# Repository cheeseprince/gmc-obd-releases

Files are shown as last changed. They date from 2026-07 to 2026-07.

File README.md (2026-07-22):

# GMC OBD Display — OTA Releases

Firmware release channel for an in-cab OBD-II stat display on a **2025 GMC Sierra 1500
3.0L Duramax** (LZ0, Global B). Binaries only — source is maintained privately.

The display shows live engine, transmission, aftertreatment and economy data pulled over
Bluetooth LE from a generic ELM327 adapter, including enhanced GM Mode-22 parameters
(transmission temperature, EGT, DPF differential pressure, fuel rail pressure, DEF level)
that generic scan tools do not expose.

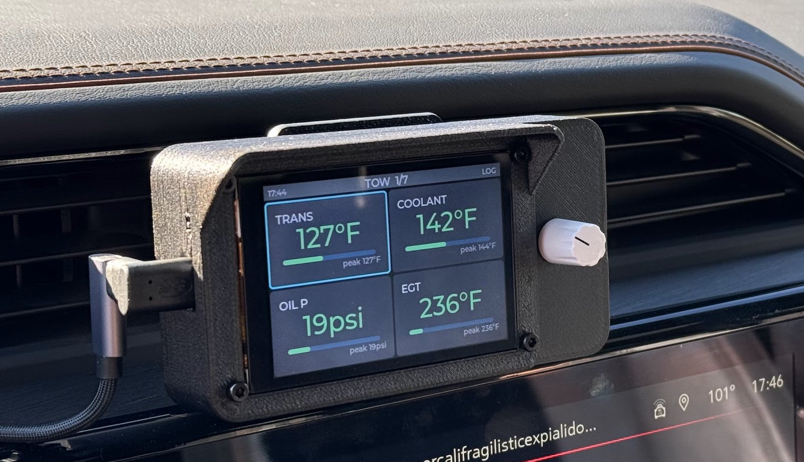
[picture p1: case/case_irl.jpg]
The unit installed on the dash, showing the towing page


## Hardware

| Part | Detail |
| :--- | :--- |
| **Display / MCU** | Elecrow **CrowPanel Advance 3.5"** — ESP32-S3-WROOM-1-N16R8 (16 MB flash, 8 MB PSRAM), 480×320 IPS |
| **Input** | Arduino **Modulino** rotary encoder (I²C) — rotate to move, press to zoom, long-press for settings |
| **Encoder cable** | **SparkFun Qwiic-to-Grove adapter cable, 100 mm** (`B082MM52ZR`) — the board exposes a Grove/Crowtail I²C port, the Modulino uses Qwiic; this bridges them |
| **Storage** | **microSD** card (FAT32) — 1 Hz CSV drive logs |
| **Clock** | On-board **PCF8563** real-time clock (I²C 0x51) with its coin cell — both ship with the CrowPanel. Timestamps the SD logs and drives automatic day/night theming |
| **OBD adapter** | **Vgate vLinker MS** in BLE mode (classic-CAN ELM327) — see tested adapters below |
| **Power** | Truck USB (switched 5 V) → board USB-C |
| **Case** | 3D printed — STLs in [`case/`](case/) — plus **8 × M3 heat-set threaded inserts** (4 mm long, 5 mm OD) and **8 × M3 × 10 mm screws** |

The capacitive touch panel is present but unused; all navigation is via the encoder.

### Case

Three-part printed enclosure — the CAD assembly, and the printed result on the dash
above.

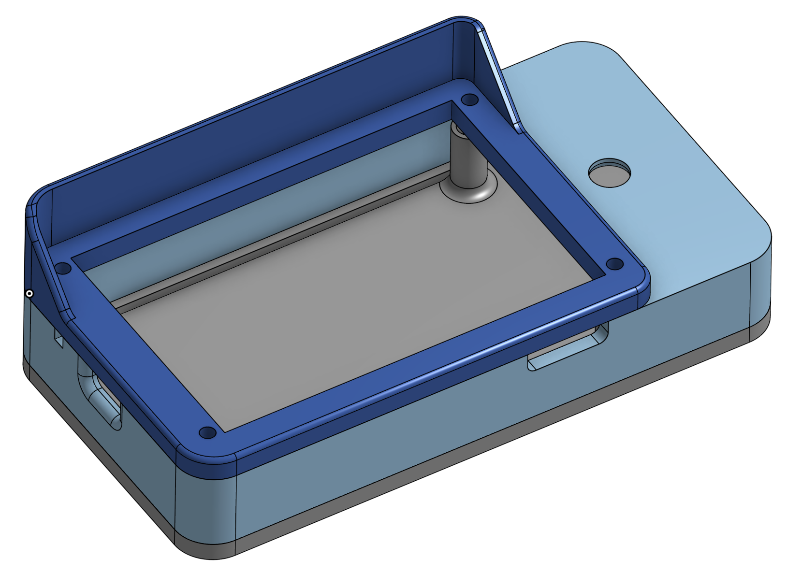
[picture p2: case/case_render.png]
Case assembly


Three printed parts: a bottom shell that carries the board on moulded standoffs, a frame
that captures the display bezel, and a top. Heat-set the inserts into the bottom, then the
screws pass down through the top and frame into them.

| Part | Footprint | STL |
| :--- | :--- | :--- |
| Top | 131.4 × 69.4 × 17.0 mm | [`CASE_TOP.stl`](case/CASE_TOP.stl) |
| Frame | 102.8 × 69.4 × 20.0 mm | [`CASE_FRAME.stl`](case/CASE_FRAME.stl) |
| Bottom | 131.4 × 69.4 × 19.0 mm | [`CASE_BOTTOM.stl`](case/CASE_BOTTOM.stl) |

Fasteners: **8 × M3 heat-set threaded inserts** (4 mm long, 5 mm OD) and
**8 × M3 × 10 mm screws**. Everything fits a 140 mm bed.

## Tested OBD adapters

Both were verified on the vehicle. **Addressing turned out to be adapter-dependent on
this truck** — worth knowing before assuming a working adapter implies a working
protocol configuration.

| Adapter | Link | Result |
| :--- | :--- | :--- |
| **Vgate vLinker MS** | BLE | **In use.** Reads enhanced GM Mode-22 with **11-bit** headers (`7DF` functional, `7E0` engine, `7E2` transmission). Also works in classic-Bluetooth mode on ESP32 (non-S3) boards. |
| **Vgate iCar Pro WiFi** | Wi-Fi SoftAP | **Works, but only on 29-bit CAN.** Same truck, same PIDs, different addressing: ISO 15765-4 29-bit/500k (`18DB33F1` functional, `18DAxxF1` physical). Defaults: SSID `V-LINK`, TCP `192.168.0.10:35000`. |

Notes from bring-up:

- The vLinker MS ships in **Classic/MFi-only** mode. An ESP32-**S3** has no classic
  Bluetooth, so the adapter must first be switched to BT+BLE mode with Vgate's
  `VgateFwUpdater` app — a one-time change. Its ELM327 service is GATT `0x18F0`
  (notify `0x2AF0`, write `0x2AF1`).
- A generic adapter's protocol auto-search is aborted by **any** host character, so the
  first `0100` after `ATSP0` needs a multi-second window. A short timeout latches the
  wrong protocol and every PID then returns `NO DATA`.
- A single BLE OBD adapter bonds to **one** client at a time.

## The display

Pixel-exact renders of the real firmware UI — generated on the build machine by
compiling the actual UI code against LVGL, so they match the panel exactly.

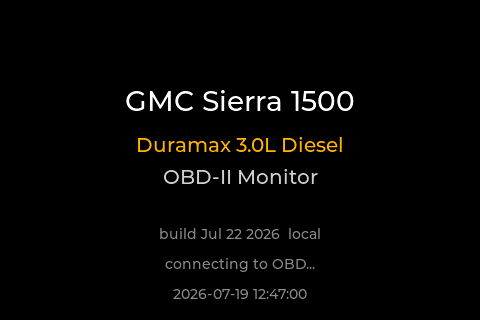
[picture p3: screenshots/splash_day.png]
Boot splash


Seven pages of four tiles, grouped by what you're doing. Rotate the encoder to move the
cursor; it flows across pages in reading order.

| TOW | POWER |
| :---: | :---: |
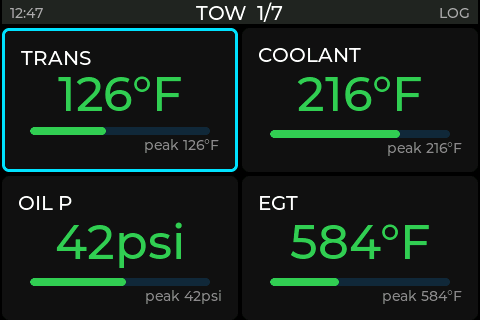
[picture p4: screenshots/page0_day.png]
TOW page
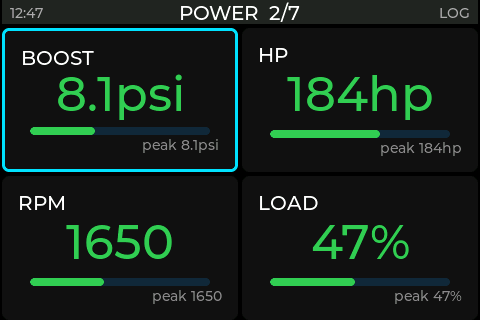
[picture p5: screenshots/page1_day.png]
POWER page
|  |  |
| Transmission · coolant · oil pressure · EGT | Boost · horsepower · RPM · engine load |

| REGEN | RANGE |
| :---: | :---: |
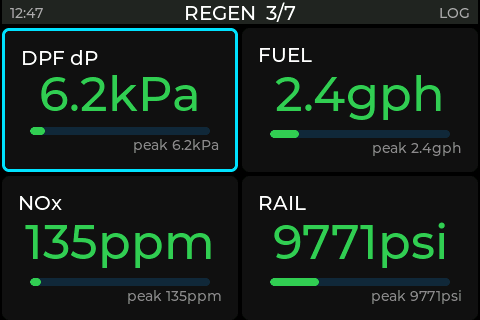
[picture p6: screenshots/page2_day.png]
REGEN page
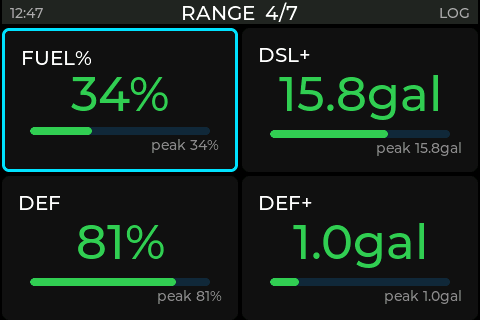
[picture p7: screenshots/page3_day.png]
RANGE page
|  |  |
| DPF Δp · fuel rate · NOx · rail pressure | Fuel and DEF level, plus gallons-to-fill |

| TRIP | DIAG | MISC |
| :---: | :---: | :---: |
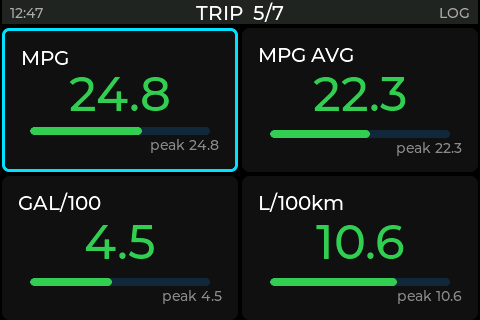
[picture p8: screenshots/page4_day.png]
TRIP page
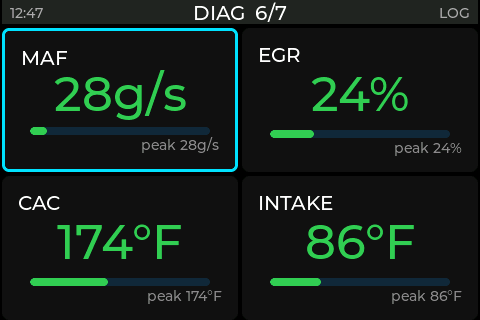
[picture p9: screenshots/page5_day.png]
DIAG page
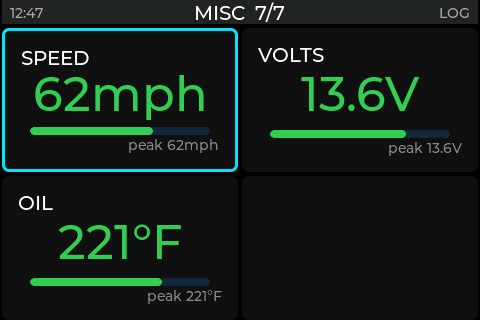
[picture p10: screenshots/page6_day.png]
MISC page
|  |  |  |
| Instant and average economy, in both US and metric units | MAF · EGR · charge-air cooler temp · intake temp | Speed · battery voltage · oil temperature |

Press the encoder to zoom a single tile, with a five-minute trend graph coloured by alarm
zone. Hold it for settings.

| Focus view | Settings |
| :---: | :---: |
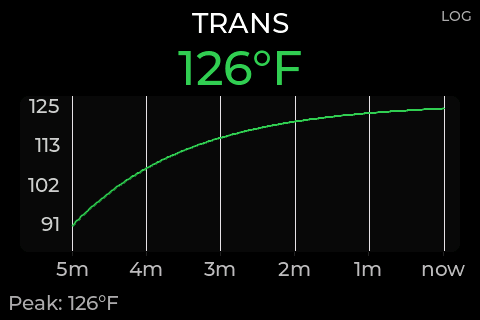
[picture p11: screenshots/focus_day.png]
Focus view
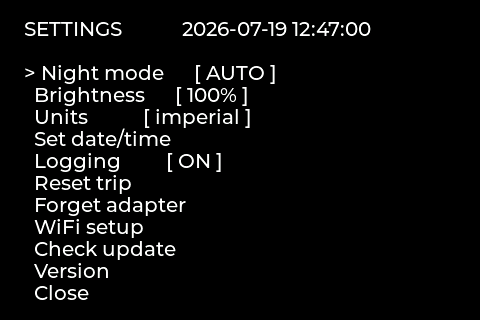
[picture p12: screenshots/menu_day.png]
Settings menu
|  |  |

The theme follows sunrise and sunset automatically, computed on-device from the real-time
clock — no light sensor. Units switch between imperial and metric from the menu.

| Night theme | Metric |
| :---: | :---: |
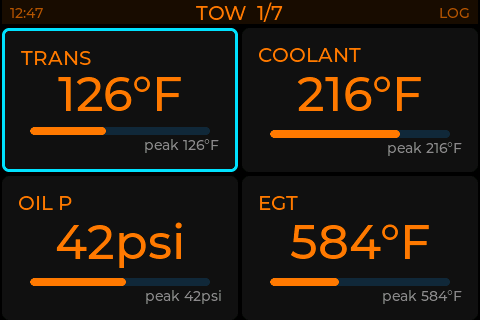
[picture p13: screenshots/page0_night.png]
Night theme
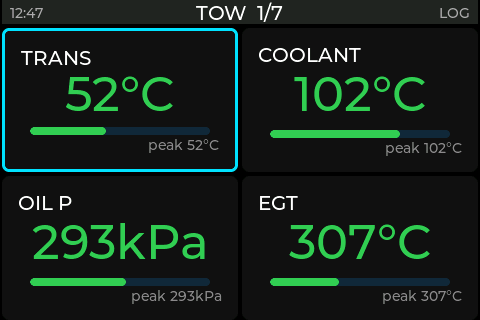
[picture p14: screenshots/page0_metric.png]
Metric units
|  |  |

Every render, including the focus-cursor and metric variants of the other pages, is in
[`screenshots/`](screenshots/).

## How updates work

Devices fetch `manifest.txt` over HTTPS (GitHub Pages), compare the release git hash
against their running build, and self-update via ESP32 dual-slot OTA. The downloaded
image is **SHA-256 verified before the slot is activated**; any failure leaves the running
slot untouched.

Manifest format — one line per release:

```
<env> <git-hash> <sha256> <size-bytes> <filename>
```

Published by `publish_ota.sh` from the build machine. **Do not edit by hand.**

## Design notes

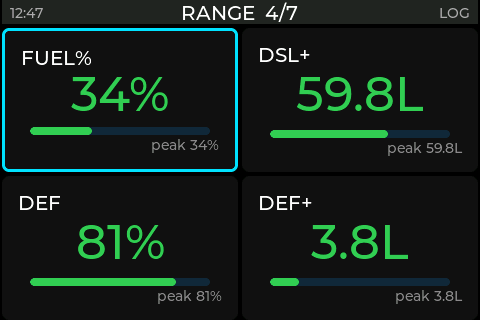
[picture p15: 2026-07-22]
screenshots/page3_metric.png

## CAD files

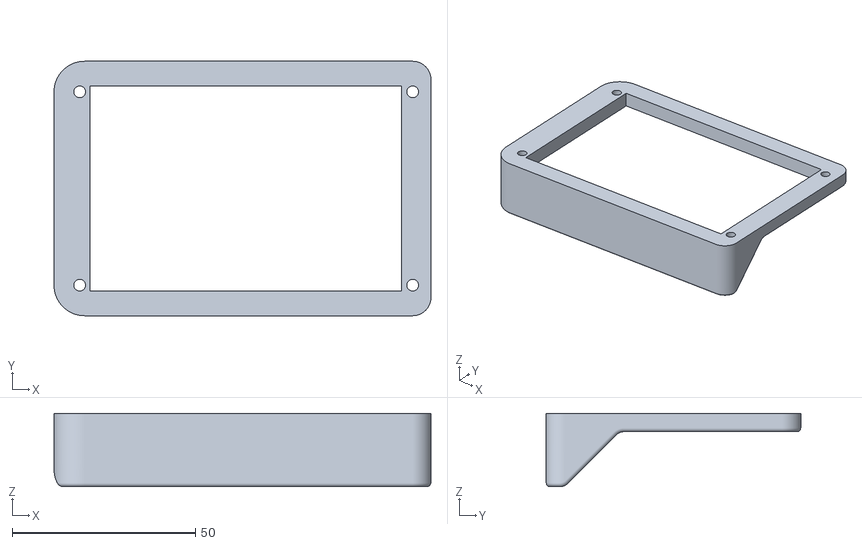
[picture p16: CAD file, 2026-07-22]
case/CASE_FRAME.stl
102.8 x 69.4 x 20.0

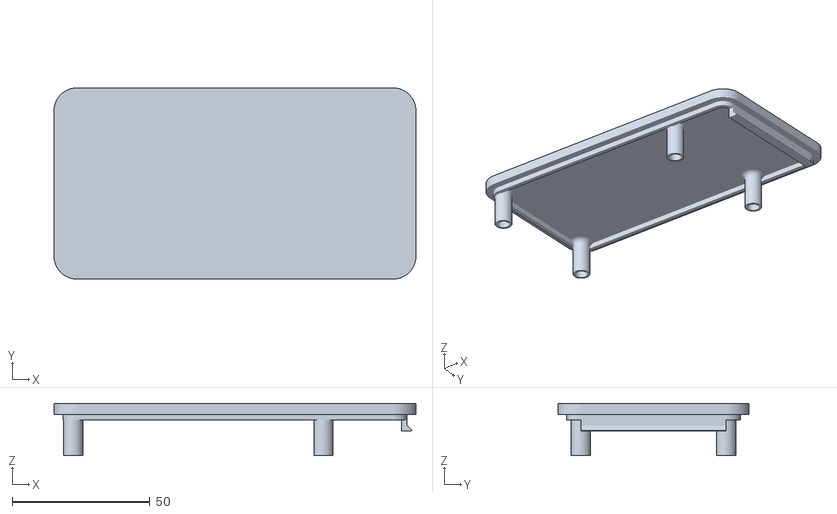
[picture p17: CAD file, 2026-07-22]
case/CASE_BOTTOM.stl
131.4 x 69.4 x 19.0

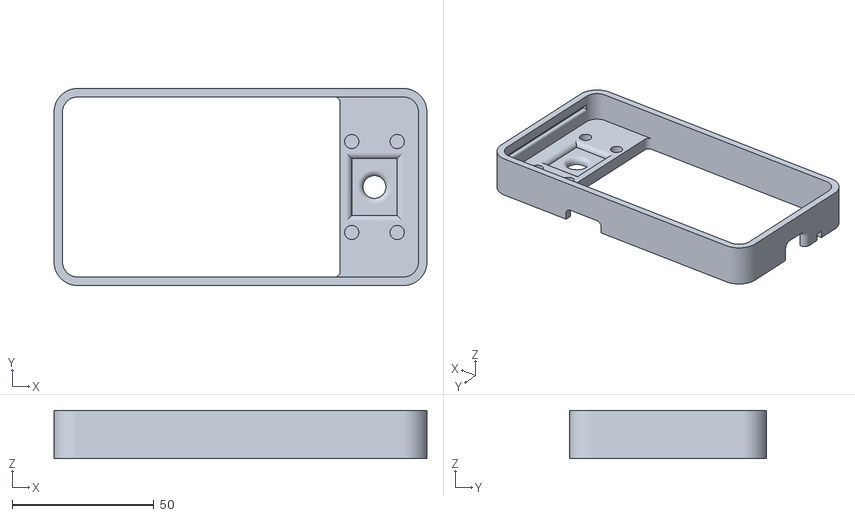
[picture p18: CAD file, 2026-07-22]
case/CASE_TOP.stl
131.4 x 69.4 x 17.0

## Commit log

2026-07-22 docs: dash-only README + UI screenshots; drop orphaned knob bin
    The Waveshare knob moved to the Sonos project (2026-07-16) and publish_ota.sh
    stopped shipping its binary, but the already-committed wsknob_wifi.bin was
    never removed. Delete it — no manifest entry referenced it, so no device
    could reach it.
    manifest.json was a never-populated placeholder; the firmware fetches
    manifest.txt (src/ota_update.cpp), so it was dead and misleading.
    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
2026-07-22 docs: add encoder adapter cable + tested OBD adapter list
    The Grove-to-Qwiic cable is a required part nobody would infer from the BOM:
    the CrowPanel exposes Grove/Crowtail I2C, the Modulino encoder uses Qwiic.
    Tested-adapter table records the adapter-dependent addressing finding —
    the vLinker MS reads this truck on 11-bit headers while the iCar Pro WiFi
    only answers on 29-bit, same vehicle and same PIDs.
2026-07-22 docs: RTC is on-board the CrowPanel, not a separate part
    Only the coin cell needs sourcing; the PCF8563 ships on the board.
2026-07-22 feat(case): add 3D-printable enclosure STLs + fastener BOM
    Three-part printed case (top, frame, bottom). Assembly needs 8 M3 heat-set
    threaded inserts (4x5) and 8 M3x10 screws. Footprints listed in the README
    so the print bed requirement is obvious before downloading 3.7 MB of STL.
    [CASE_BOTTOM.stl, CASE_FRAME.stl, CASE_TOP.stl]
2026-07-22 docs(case): add CAD assembly render, restructure case section
    Alan's CAD render shows the parts in assembled relationship — display
    aperture, screw bosses, USB cutouts — which flat single-part renders miss.
2026-07-22 docs: focus render now shows a populated trend graph; clock parts ship with the board
    The focus screenshot was rendered with an empty history ring, so its trend
    graph pane was blank — it now seeds a 5-minute warm-up curve and shows trans
    temp climbing 91->126F with real axis values.
